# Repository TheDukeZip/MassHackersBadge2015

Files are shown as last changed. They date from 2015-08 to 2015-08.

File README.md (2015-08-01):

# MassHackersBadge2015

## Programming

The stock firmware is written in the Arduino IDE. Before making modifications, you should make sure you can properly flash the stock code before going wild. You will need:

* Arduino IDE (Recommend 1.6.5)
* <a href="https://www.pjrc.com/teensy/td_download.html">Teensyduino</a> plugin for Arduino

During the Teensyduino plugin, it will ask you any additional libraries you wish to install. **You must minimally install the SoftPWM library**, which is a pulse width modulation library which allows the badge to fade the LEDs in and out instead of just turn them on and off.

When flashing the Teensy module, use the following settings found under the Arduino menu *Tools*

* Board: "Teensy 2.0"
* CPU Speed: "8 MHz"

It is **VERY IMPORTANT** to set the speed to *8 MHz* or lower. Your teensy board is modified to operate at 3.3 volts instead of the default 5 volts. **Running at the default 16MHz is OVERCLOCKING** the processor, which will probably work fine for a while, but I can't guarantee how long it will last in the desert heat. Don't freak out if you do it by accident and the LEDs flash extra fast, just reflash again with the correct clock speed.

The Arduino IDE will then prompt you to press the reset button on the Teensy module, after which it will flash the board. You must press the reset button, since access to the bootloader through USB is disabled in the badge firmware to save power.

The Teensy module can be removed from the badge, and is populated with headers so you can pop it into a breadboard and use it for any other project you desire. Remember it has been modified to run at 3.3 volts, if you need to switch it back to 5 volts for other uses, <a href="https://www.pjrc.com/teensy/3volt.html">follow the instructions here at the part "If you decide to switch back to 5 volts..."</a>

## Firmware

### Adding a new color into the rotation
* Insert color into the `LED_COLOR` enum of the header file, ideally somewhere before `LED_COLOR_WHITE`
* Insert the RGB color values into the main file, `LEDColorMap` in the order it was inserted into `LED_COLOR` You will also need to increase the array size to accomodate this

That's it! The color automatically gets inserted into the rotation upon flashing. There is a trick to the SoftPWM library. Let's say for example you create a color that is RED 127, GREEN 255, BLUE 0. And your fade in time is 1000ms. The red and green fade in at the same rate, so red reaches its full brightness after 500ms, but green continues to fade in for an additional 500ms. You can overcome this by individually setting the fade in/out component of the red portion of the LED to be double that of the green portion of the LED. I started some work on this in the function `offLEDCorrected()` but it is up to you to finish it, and write a complementary function for turning on the LEDs!

### Adding a new mode into the rotation
* Insert the mode into the `LED_MODE` enum of the header file, which *must* be before `LED_MODE_END`
* Set the LED fade in and fade out times for your mode in `LEDModeFadeTimes` in the main file. You will also need to change the size of the array to accomodate this
* Create a handler function that does whatever you want to the LEDs - See other modes for examples
* Add a call to your handler function in the main `loop()` case statement: `switch(currentMode)`

The button presses are not interrupt based, you should plan to call the function `checkButton()` at least after every 50ms during your mode. (This is not truely a 50ms delay due to running at 8MHz, it is closer to 100ms)

## Hardware

Schematic and PCB was designed in Eagle 6.6.0. Eagle does not pre-load the ground pours when loading the PCB design. After opening the PCB you should run the "rats nest" tool to populate the ground pours.

You can remove the Teensy 2.0 module from the badge and put it into a breadboard for other fun hardware projects. The Teensy board is modified to operate at 3.3 volts, if you need to switch it back to 5 volts for other uses, <a href="https://www.pjrc.com/teensy/3volt.html">follow the instructions here at the part "If you decide to switch back to 5 volts..."</a>

### Errata

* Resistors for RED LEDs are R13 through R18 and should be 150 ohms
* Resistors for GREEN and BLUE LEDs are R1 through R12 and should be 15 ohms
* For the RGB LEDs in the BOM, the LED should be soldered on the board with the pin 1 marker on the bottom left, not the top right as on the silk screen

### BOM
| Qty | Description | MPN | Digikey PN |
|-----|---|-----|---|
| 1 | Teensy 2.0  | - |  - |
| 6 | RGB LED | CLVBA-FKA-CAEDH8BBB7A363 | CLVBA-FKA-CAEDH8BBB7A363CT-ND |
| 6 | 150 ohm 0603 resistor | RMCF0603FT150R | RMCF0603FT150RCT-ND |
| 12  | 15 ohm 0603 resistor  | RMCF0603FT15R0 | RMCF0603FT15R0CT-ND | 
| 1 | Voltage regulator for Teensy | MCP1825S-3302E/DB | MCP1825S-3302E/DB-ND |
| 2 | Header for Teensy board | PREC012SAAN-RC | S1012EC-12-ND |
| 2 | Socket for badge PCB | 929974-01-12-RK | 929974E-01-12-ND |
| 1 | CR123A Battery Holder | 1019 | 36-1019-ND |
| 1 | Momentary Switch | KMR231NG LFS | CKN10246CT-ND |

### Files

Eagle Project: **Hardware/MassHackersBadge2015.pro**<br>
Eagle Schematic: **Hardware/MassHackersBadge2015.sch**<br>
Eagle PCB: **Hardware/MassHackersBadge2015.brd**

Gerbers for manufacturing: **Hardware/Gerbers**

Design rule check and CAM file for Gerber generation for DirtyPCBs: **Hardware/DirtyPCBs**

### Available Hardware Pins

There are <a href="https://www.pjrc.com/teensy/pinout.html">3 pins</a> available on the Teensy 2.0 to add additional hardware:
* Pin 9 - Digital I/O
* Pin 10 - Digital I/O
* Pin 11 - Analog or Digital I/O

You will need to remove pins you use from the array `UnusedPins` so they do not get disabled during the power conservation routine

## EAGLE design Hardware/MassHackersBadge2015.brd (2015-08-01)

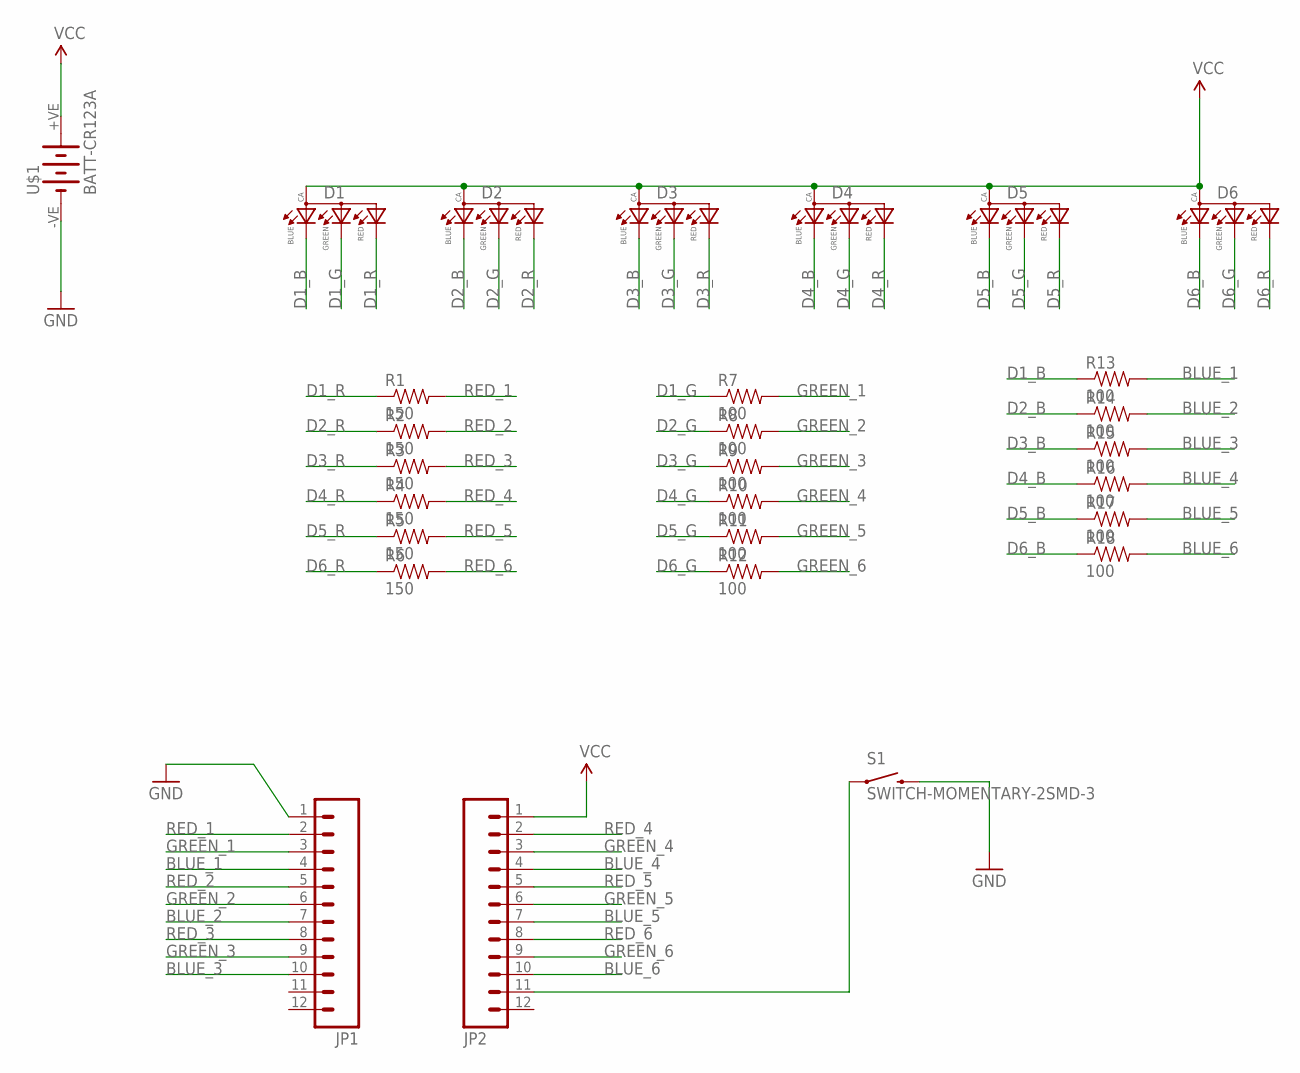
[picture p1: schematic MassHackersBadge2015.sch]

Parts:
D1, D2, D3, D4, D5, D6: 0.13_RGB_LEDPLCC; P-LCC-4-3
JP1, JP2: M12PTH; 1X12
R1, R2, R3, R4, R5, R6: 150; 0603-RES
R7, R8, R9, R10, R11, R12, R13, R14, R15, R16, R17, R18: 100; 0603-RES
S1: SWITCH-MOMENTARY-2SMD-3; TACTILE_SWITCH_SMD-3
U$1: BATT-CR123A; KEYSTONE-2/3A

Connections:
BLUE_1: JP1.4, R13.2
BLUE_2: JP1.7, R14.2
BLUE_3: JP1.10, R15.2
BLUE_4: JP2.4, R16.2
BLUE_5: JP2.7, R17.2
BLUE_6: JP2.10, R18.2
D1_B: D1.3 (BLUE), R13.1
D1_G: D1.2 (GREEN), R7.1
D1_R: D1.1 (RED), R1.1
D2_B: D2.3 (BLUE), R14.1
D2_G: D2.2 (GREEN), R8.1
D2_R: D2.1 (RED), R2.1
D3_B: D3.3 (BLUE), R15.1
D3_G: D3.2 (GREEN), R9.1
D3_R: D3.1 (RED), R3.1
D4_B: D4.3 (BLUE), R16.1
D4_G: D4.2 (GREEN), R10.1
D4_R: D4.1 (RED), R4.1
D5_B: D5.3 (BLUE), R17.1
D5_G: D5.2 (GREEN), R11.1
D5_R: D5.1 (RED), R5.1
D6_B: D6.3 (BLUE), R18.1
D6_G: D6.2 (GREEN), R12.1
D6_R: D6.1 (RED), R6.1
GND: JP1.1, S1.4 (2), U$1.-VE (-)
GREEN_1: JP1.3, R7.2
GREEN_2: JP1.6, R8.2
GREEN_3: JP1.9, R9.2
GREEN_4: JP2.3, R10.2
GREEN_5: JP2.6, R11.2
GREEN_6: JP2.9, R12.2
unnamed: JP2.11, S1.1
RED_1: JP1.2, R1.2
RED_2: JP1.5, R2.2
RED_3: JP1.8, R3.2
RED_4: JP2.2, R4.2
RED_5: JP2.5, R5.2
RED_6: JP2.8, R6.2
VCC: D1.4 (ANODE), D2.4 (ANODE), D3.4 (ANODE), D4.4 (ANODE), D5.4 (ANODE), D6.4 (ANODE), JP2.1, U$1.+VE (+)

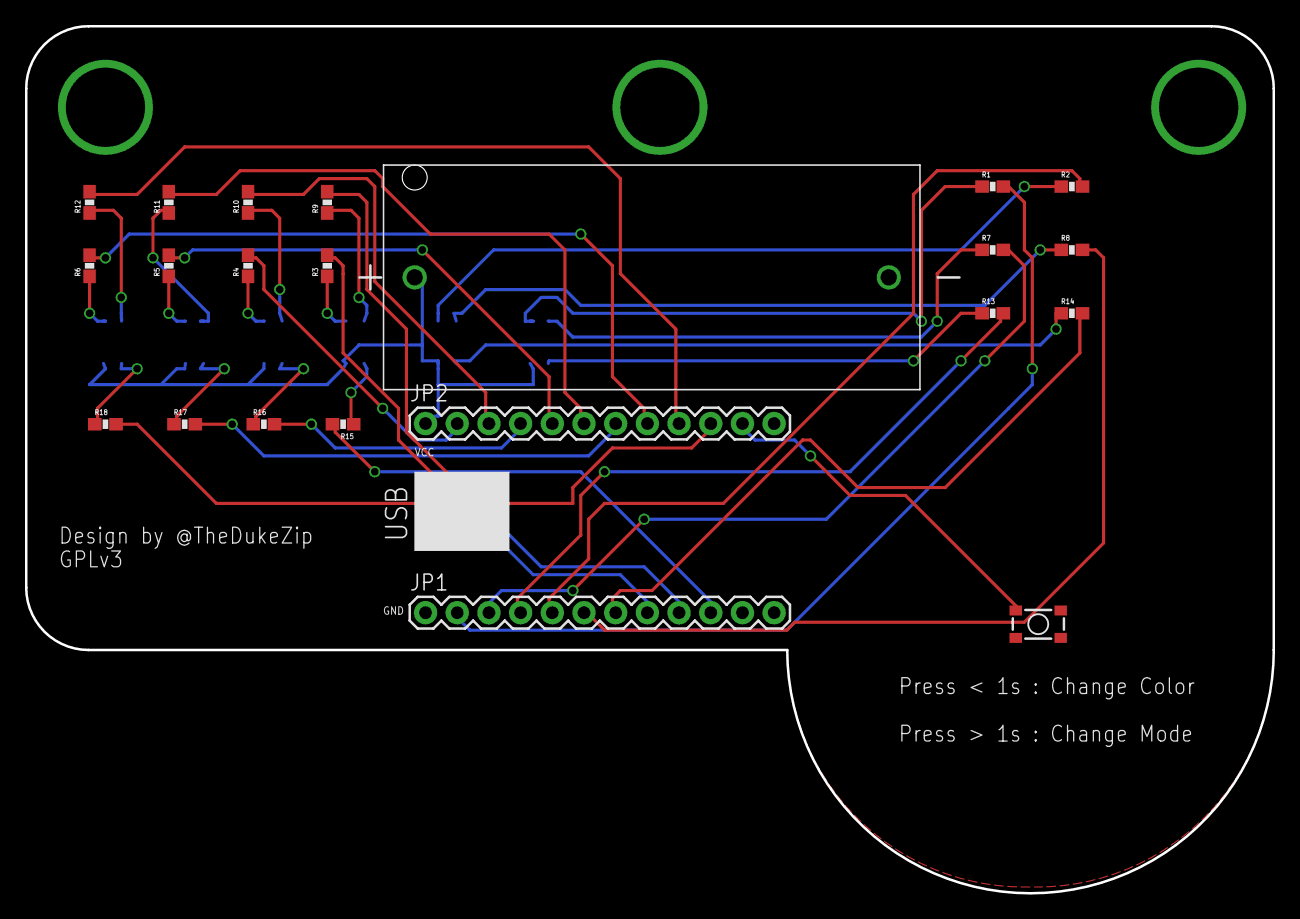
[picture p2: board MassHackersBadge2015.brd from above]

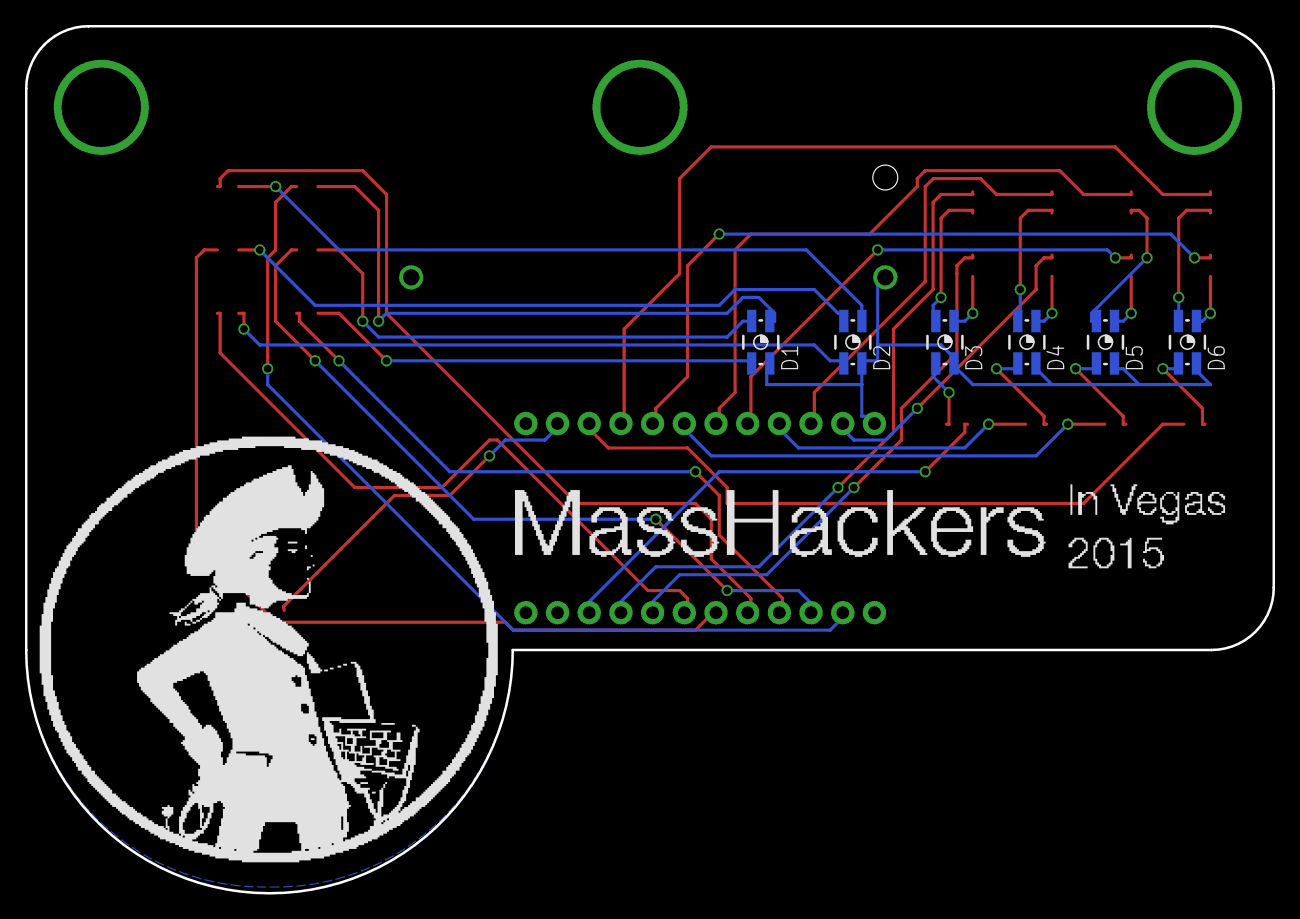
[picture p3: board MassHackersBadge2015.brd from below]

Board: 2 copper layers, 100.0 x 69.5 mm, 28 parts (6 on the bottom side), 39 nets.

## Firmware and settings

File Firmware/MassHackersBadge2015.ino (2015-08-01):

#include <SoftPWM.h>
#include <SoftPWM_timer.h>
#include <EEPROM.h>

#include "MassHackersBadge.h"


/////////////////////////////////////////////////////
//
// DEFINITIONS
//
/////////////////////////////////////////////////////

#define LED_BRIGHTNESS 1                        //Turn down the brightness - 0.5 = 50%   0.25 = 25% etc.

#define NUMBER_OF_LEDS 6                        //Number of LEDs on the badge to use

#define EEPROM_COLOR_LOCATION 0                 //Location in EEPROM to save color setting
#define EEPROM_MODE_LOCATION  1                 //Location in EEPROM to save mode setting
#define MAIN_LOOP_SAVE_ITERATIONS 60            //How many iterations through the main loop to check if you've changed the settings, and save them

#define BUTTON_PIN 12                           //Which pin is connected to the button?

#define CELLULAR_AUTOMATON_WIDTH 66             //Size of the array to store the cellular automaton state
#define CELLULAR_AUTOMATON_REPEAT_THRESHOLD 3   //If the LEDs for cellular automaton stabilize for this many iterations, reset the array
#define CELLULAR_AUTOMATON_OFFSET 30            //Offset in cellular automaton array to display

#define POWER_CONSERVATION_ENABLE true          //Turns off unneeded peripherals on MCU
#define NUM_UNUSED_PINS 3                       //Define the unused pins we can set to output mode to save some power
uint8_t UnusedPins[NUM_UNUSED_PINS] = { 9, 10, 11 };

//Two-dimensional array specifying LED pins
// Each row represents an LED, array within represent pin for R, G, B in that order
// Do not change these unless you use the code with hardware other than the MassHackers 2015 badge
// See this page for pinouts: https://www.pjrc.com/teensy/pinout.html
uint8_t LEDS[6][3] = {
                      {2, 1, 0},  //D1 { R, G, B }
                      {5, 4, 3},  //D2 { R, G, B }
                      {8, 7, 6},  // etc.
                      {19, 20, 21},
                      {16, 17, 18},
                      {13, 14, 15}
};

//Map values of R, G, B, for each LED_COLOR defined in header file
uint8_t LEDColorMap[10][3] = {
                              {  0, 255,   0}, //LED_COLOR_GREEN
                              {  0,   0, 255}, //LED_COLOR_BLUE
                              {255,   0,   0}, //LED_COLOR_RED
                              {  0, 255, 255}, //LED_COLOR_CYAN
                              {255, 255,   0}, //LED_COLOR_YELLOW
                              {255,   0, 255}, //LED_COLOR_PURPLE
                              {255, 255, 255}, //LED_COLOR_WHITE
                              {255, 255, 255}, //LED_COLOR_SEQUENTIAL Just a placeholder
                              {255, 255, 255}  //LED_MODE_MULTI       Just a placeholder
};

//Map of fade in , fade out times for each LED_MODE defined in header file
uint16_t LEDModeFadeTimes[9][2] = {
                                {  50, 400 }, //LED_MODE_SCAN
                                {  50, 400 }, //LED_MODE_SCAN_CONSTANT
                                {2000,2000 }, //LED_MODE_PULSE
                                {  50, 200 }, //LED_MODE_HEARTBEAT
                                { 600, 400 }, //LED_MODE_CELLULAR_AUTOMATON
                                {   0, 500 }, //LED_MODE_TWINKLE
                                {   0, 100 }, //LED_MODE_BOOTS_AND_PANTS
                                {   0,  50 }, //LED_MODE_VU_METER
                                {   0, 500 }  //LED_MODE_PARTY_SHUFFLE
};


uint8_t cells[CELLULAR_AUTOMATON_WIDTH];          //Array to store the cellular automaton status

uint8_t ruleset[8] = { 0, 0, 0, 1, 1, 1, 1, 0 };  //Cellular automaton ruleset - default is RULE 30 (Chaotic)
                                                  //See http://mathworld.wolfram.com/ElementaryCellularAutomaton.html for diagrams of all rules

uint8_t cellular_automaton_repeat_count = 0;      //Store the number of times the cellular automaton LEDs have repeated


/////////////////////////////////////////////////////
//
// SETUP AND MAIN LOOP
//
/////////////////////////////////////////////////////
LED_COLOR currentColor = LED_COLOR_GREEN;
LED_MODE currentMode = LED_MODE_SCAN;

LED_COLOR currentSequentialColor = LED_COLOR_GREEN;

int saveCounter = 0;
  
void setup() 
{
  //Start saving power
  if(POWER_CONSERVATION_ENABLE) startPowerSave();
   
  //Set up SoftPWM
  SoftPWMBegin(SOFTPWM_INVERTED); //LEDs have a common anode, pull LOW to turn them ON (inverted)
  for (int i = 0; i < NUMBER_OF_LEDS; i++)
  {
    for (int j = 0; j < 3; j++)
      SoftPWMSet(LEDS[i][j], 0);
  }
  SoftPWMSetFadeTime(ALL, 50, 400);

  //Set up button
  pinMode(BUTTON_PIN, INPUT);
  digitalWrite(BUTTON_PIN, HIGH); 

  //Restore settings
  restoreSettings();

  //Initialize cellular automaton array
  initializeCellularAutomaton();
}

void loop() 
{
  
  switch(currentMode) {
    case LED_MODE_SCAN:
      scan();
      break;

     case LED_MODE_SCAN_CONSTANT:
      scan_constant();
      break;

     case LED_MODE_PULSE:
      pulse();
      break;

     case LED_MODE_HEARTBEAT:
      heartbeat();
      break;
      
     case LED_MODE_CELLULAR_AUTOMATON:
      cellular_automaton();
      break;
      
     case LED_MODE_TWINKLE:
      twinkle();
      break;

     case LED_MODE_BOOTS_AND_PANTS:
      boots_and_pants();
      break;

     case LED_MODE_VU_METER:
      vu_meter();
      break;

     case LED_MODE_PARTY_SHUFFLE:
      party_shuffle();
      break;

     case LED_MODE_END: //Should never get here, but disables the warning in the compiler
      break;
  }

  //Save settings occasionally
  if(++saveCounter >= MAIN_LOOP_SAVE_ITERATIONS)
  {
    saveSettings();
    saveCounter = 0;
  }

  //If you're in sequential color mode, change the color on every iteration of the loop
  if(currentColor == LED_COLOR_SEQUENTIAL)
    changeSequentialColor();
}


/////////////////////////////////////////////////////
//
// LIGHTING MODE PROGRAMMING
//
//
// One handler function per mode
// Functions are called by the main loop() above
//
/////////////////////////////////////////////////////

//OCCASIONAL CYLON / KITT STYLE SCANNER
void scan() 
{
  int i;
  
  setLED(0, currentColor);

  delay(50);
  for (i = 0; i < NUMBER_OF_LEDS - 1; i++)
  {
    setLED(i+1, currentColor);
    offLED(i);
    delay(50);
    if(checkButton()) return;
  }

  for (int t = 0; t < 4; t++)
  {
    delay(50);
    if(checkButton()) return;
  }
  
  for (i = NUMBER_OF_LEDS - 1; i > 0; i--)
  {
    setLED(i-1, currentColor);
    offLED(i);
    delay(50);
    if(checkButton()) return;
  }

  offLED(0);
  
  for (int t = 0; t < 20; t++)
  {
    delay(50);
    if (checkButton()) return;
  }
}

//CONSTANT CYLON / KITT STYLE SCANNER
void scan_constant() 
{
  int i;
  
  setLED(0, currentColor);

  delay(50);
  for (i = 0; i < NUMBER_OF_LEDS - 1; i++)
  {
    setLED(i+1, currentColor);
    offLED(i);
    delay(50);
    if (checkButton()) return;
  }

  for (int t = 0; t < 4; t++)
  {
    delay(50);
    if (checkButton()) return;;
  }
  
  for (i = NUMBER_OF_LEDS - 1; i > 0; i--)
  {
    setLED(i-1, currentColor);
    offLED(i);
    delay(50);
    if(checkButton()) return;
  }

  for (int t = 0; t < 4; t++)
  {
    delay(50);
    if (checkButton()) return;
  }
}

//PULSE
void pulse()
{
  int i;
  
  for(i = 0; i < NUMBER_OF_LEDS; i++)
  {
    setLED(i, currentColor);
  }

  for (int t = 0; t < 16; t++)
  {
    delay(50);
    if (checkButton()) return;
  }
  
  for(i = 0; i < NUMBER_OF_LEDS; i++)
  {
    offLED(i);
  }

  for (int t = 0; t < 30; t++)
  {
    delay(50);
    if (checkButton()) return;
  }
}

//HEARTBEAT
void heartbeat()
{
  int i;
  
  for(i = 3; i < NUMBER_OF_LEDS; i++)
  {
    setLED(i, currentColor);
    setLED(5 - i, currentColor);
  }

  delay(50);
  if (checkButton()) return;  

  for(i = 0; i < NUMBER_OF_LEDS / 2; i++)
  {
    offLED(i);
    offLED(5 - i);
  }

  if (checkButton()) return; 
  
  for(i = 3; i < NUMBER_OF_LEDS; i++)
  {
    setLED(i, currentColor);
    setLED(5 - i, currentColor);
  }

  delay(50);
  if (checkButton()) return;  

  for(i = 0; i < NUMBER_OF_LEDS / 2; i++)
  {
    offLED(i);
    offLED(5 - i);
  }
  
  for (int t = 0; t < 30; t++)
  {
    delay(50);
    if (checkButton()) return;
  }
}

//CELLULAR AUTOMATON
void cellular_automaton() 
{
  int i;
  bool LEDs_repeated = true;
  uint8_t newcells[CELLULAR_AUTOMATON_WIDTH];  

  //Turning off the LEDs, then on, seems to be more visually appealing than doing it all in one loop
  for(i = 0; i < NUMBER_OF_LEDS; i++)
  {
    if(!cells[i + CELLULAR_AUTOMATON_OFFSET])
      offLED(i);
  }
  for(i = 0; i < NUMBER_OF_LEDS; i++)
  {
    if(cells[i + CELLULAR_AUTOMATON_OFFSET])
      setLED(i, currentColor);
  }
      
  for(i = 1; i < CELLULAR_AUTOMATON_WIDTH - 2; i++)
  {
    uint8_t left = cells[i-1];
    uint8_t middle = cells[i];
    uint8_t right = cells[i+1];

    newcells[i] = cellular_automaton_rules(left, middle, right);
  }

  //Far left cell
  newcells[0] = cellular_automaton_rules(0, cells[0], cells[1]);

  //Far right cell
  newcells[CELLULAR_AUTOMATON_WIDTH - 1] = cellular_automaton_rules(cells[CELLULAR_AUTOMATON_WIDTH - 2], cells[CELLULAR_AUTOMATON_WIDTH - 1], 0);

  //Check and see if the LEDs repeated
  for(i = 0; i < NUMBER_OF_LEDS; i++)
  {
    if(newcells[i + CELLULAR_AUTOMATON_OFFSET] != cells[i + CELLULAR_AUTOMATON_OFFSET])
      LEDs_repeated = false;
  }
  if(LEDs_repeated) 
    cellular_automaton_repeat_count++;

  memcpy(cells, newcells, CELLULAR_AUTOMATON_WIDTH * sizeof(char)); // I know you just did a double take. I put that there just to make you smile  ;)

  if (checkButton()) return;
  for (int t = 0; t < 20; t++)
  {
    delay(50);
    if (checkButton()) return;
  }

  //If the LEDs repeated too many times, reset the array
  if(cellular_automaton_repeat_count >= CELLULAR_AUTOMATON_REPEAT_THRESHOLD)
    initializeCellularAutomaton();
}
uint8_t cellular_automaton_rules(uint8_t a, uint8_t b, uint8_t c)
{
    if      (a == 1 && b == 1 && c == 1) return ruleset[0];
    else if (a == 1 && b == 1 && c == 0) return ruleset[1];
    else if (a == 1 && b == 0 && c == 1) return ruleset[2];
    else if (a == 1 && b == 0 && c == 0) return ruleset[3];
    else if (a == 0 && b == 1 && c == 1) return ruleset[4];
    else if (a == 0 && b == 1 && c == 0) return ruleset[5];
    else if (a == 0 && b == 0 && c == 1) return ruleset[6];
    else if (a == 0 && b == 0 && c == 0) return ruleset[7];
    return 0;    //Should never get here!
}

//TWINKLE RANDOM COLORS ON RANDOM LEDS
//Party modes should return true if checkButton() returns true to assist with breaking out of party shuffle
bool twinkle() 
{
  int lastLED = -1; //Store last LED lit so you never twinkle the same LED twice in a row
  int led = -1;

  randomSeed(millis());

  //Party modes should last for approx 3.2s or 8 'beats' to assist with "Party Shuffle"
  for (int i = 0; i < 21; i++)
  {
    //Select random LED
    while(led == lastLED) led = random(0, NUMBER_OF_LEDS);
    lastLED = led;
  
    //Select random color
    long color = random(0, (uint8_t)LED_COLOR_WHITE + 1);   //Don't randomly select sequential / multi
  
    setLED(led, (LED_COLOR)color);
    delay(25);
    if (checkButton()) return true;
    offLED(led);
  
    delay(25);
    if (checkButton()) return true;
  }

  return false;
}

//RANDOM COLOR ALL LED FLASH AT ~120BPM
//Party modes should return true if checkButton() returns true to assist with breaking out of party shuffle
bool boots_and_pants()
{
  int i;

  randomSeed(millis());

  //Party modes should last for 8 'beats' to assist with "Party Shuffle"
  for(int j = 0; j < 8; j++)
  {
    //Select random color
    long color = random(0, (uint8_t)LED_COLOR_END);   //Randomly selecting sequential or multi is ok and gives an occasional treat
    
    for(i = 0; i < NUMBER_OF_LEDS; i++)
    {
      setLED(i, (LED_COLOR)color);
    }
  
    for(i = 0; i < NUMBER_OF_LEDS; i++)
    {
      offLED(i);
    }
  
    if (checkButton()) return true;
  }

  return false;
}

//FAKE VU METER PEAKING ~150BPM
//Party modes should return true if checkButton() returns true to assist with breaking out of party shuffle
bool vu_meter()
{
  //Party modes should last for 8 'beats' to assist with "Party Shuffle"
  for(int i = 0; i < 8; i++)
  {
    setLED(0, LED_COLOR_GREEN);
    setLED(1, LED_COLOR_GREEN);
    setLED(2, LED_COLOR_GREEN);
    setLED(3, LED_COLOR_YELLOW);
    setLED(4, LED_COLOR_YELLOW);
    setLED(5, LED_COLOR_RED);
    if (checkButton()) return true;
    
    offLED(5);
    offLED(4);
    offLED(3);
    offLED(2);
    offLED(1);
    offLED(0);
    if (checkButton()) return true;
  }

  return false;
}

//CYCLE THROUGH ALL PARTY MODES
void party_shuffle()
{
  SoftPWMSetFadeTime(ALL, LEDModeFadeTimes[(uint8_t)LED_MODE_TWINKLE][0] / LED_BRIGHTNESS, LEDModeFadeTimes[(uint8_t)LED_MODE_TWINKLE][1] / LED_BRIGHTNESS);
  if(twinkle()) return;
  SoftPWMSetFadeTime(ALL, LEDModeFadeTimes[(uint8_t)LED_MODE_BOOTS_AND_PANTS][0] / LED_BRIGHTNESS, LEDModeFadeTimes[(uint8_t)LED_MODE_BOOTS_AND_PANTS][1] / LED_BRIGHTNESS);
  if(boots_and_pants()) return;
  SoftPWMSetFadeTime(ALL, LEDModeFadeTimes[(uint8_t)LED_MODE_VU_METER][0] / LED_BRIGHTNESS, LEDModeFadeTimes[(uint8_t)LED_MODE_VU_METER][1] / LED_BRIGHTNESS);
  if(vu_meter()) return;
}

//FLASHLIGHT MODE
// Not part of mode cycle, enabled by holding button for > 5s
void flashLight()
{
  int i;

  for(i = 0; i < NUMBER_OF_LEDS; i++)
    offLED(i);

  setLED(0, LED_COLOR_WHITE);
  setLED(1, LED_COLOR_WHITE);
  setLED(2, LED_COLOR_WHITE);
  setLED(3, LED_COLOR_WHITE);
  setLED(4, LED_COLOR_WHITE);
  setLED(5, LED_COLOR_WHITE);

  delay(1000);

  //Timeout after about 30 seconds
  for(i = 0; i < 500; i++)
  {
    delay(25);
    //Or exit if user pushes button
    if(checkButtonFlashlight())
      return;
  }

  for(i = 0; i < NUMBER_OF_LEDS; i++)
  offLED(i);
}


/////////////////////////////////////////////////////
//
// HELPER FUNCTIONS
//
/////////////////////////////////////////////////////
void startPowerSave()
{
  //Disable USB - saves ~4mA at 3.3V & 8MHz
  // Reprogramming the teensy will require a press of the teensy's reboot button
  Serial.end();
  
  //Disable ADC - saves ~0.8mA
  ADCSRA = 0;

  //Set unused pins to output mode - saves ~0.4mA
  for(int i = 0; i < NUM_UNUSED_PINS; i++)
    pinMode(UnusedPins[i], OUTPUT);
}

void changeColor() 
{  
  currentColor = (LED_COLOR)((uint8_t)currentColor + 1);  
  if (currentColor == LED_COLOR_END)
    currentColor = (LED_COLOR)0;

  //Flash currently selected color to user
  if(currentColor == LED_COLOR_SEQUENTIAL || currentColor == LED_COLOR_MULTI)
  {
    //Sequential/multi sees many-colors
    for(int i = 0; i < NUMBER_OF_LEDS; i++)
      setLED(i, (LED_COLOR)i);
    delay(25);
    for(int i = 0; i < NUMBER_OF_LEDS; i++)
      offLED(i);    
  }
  else
  {
    //Otherwise just show color selected
    for(int i = 0; i < NUMBER_OF_LEDS; i++)
      setLED(i, currentColor);
    delay(25);
    for(int i = 0; i < NUMBER_OF_LEDS; i++)
      offLED(i);
  }

  //Reset the save counter so you have to leave the color on for a bit before it saves
  saveCounter = 0;
}

void changeSequentialColor() 
{  
  currentSequentialColor = (LED_COLOR)((uint8_t)currentSequentialColor + 1);  
  if (currentSequentialColor == LED_COLOR_SEQUENTIAL)
    currentSequentialColor = (LED_COLOR)0;
}

void changeMode() 
{
  currentMode = (LED_MODE)((uint8_t)currentMode + 1);
  if (currentMode == LED_MODE_END)
    currentMode = (LED_MODE)0;

  SoftPWMSetFadeTime(ALL, LEDModeFadeTimes[(uint8_t)currentMode][0] / LED_BRIGHTNESS, LEDModeFadeTimes[(uint8_t)currentMode][1] / LED_BRIGHTNESS);
    
  //Reset the save counter so you have to leave the mode on for a bit before it saves
  saveCounter = 0;
}

//Check the button state and take appropriate action
// Elite points if you modify this to use an interrupt
// but this is A) Easy for non-embedded people to understand -and-
//             B) Gives the benefit of built in debounce
// In hindsight interrupt based code probably would be easier to understand than this mess
bool checkButton() 
{
  int holdCount = 0;
  
  if (!digitalRead(BUTTON_PIN))
  {
    //User pressed the button, shut all LEDs off in preparation
    // to show feedback to user
    for(int i = 0; i < NUMBER_OF_LEDS; i++)
      offLED(i);

    //See if they let go < 1s - change color
    for(int i = 0; i < 4; i++)
    {
      delay(50);
      if (digitalRead(BUTTON_PIN))
      {
        changeColor();
        delay(50);
        return false;
      } 
    }

    //User held down for > 1s, flash for feedback to user
    //Flash currently selected color to user
    for(int i = 0; i < NUMBER_OF_LEDS; i++)
      setLED(i, currentColor);
    delay(25);
    for(int i = 0; i < NUMBER_OF_LEDS; i++)
      offLED(i);
    
    while (!digitalRead(BUTTON_PIN))
    {
      delay(50);
      holdCount++;
      //If user held down for >5s, enable flashlight
      if(holdCount > 25)
        flashLight();
    }

    //Only change mode if user didn't enable the flashlight
    if(holdCount <= 25)
      changeMode();
    return true;
  }

  return false;
}

//Check button status during flashlight mode
// If user presses button, turn off white LEDs and exit
bool checkButtonFlashlight()
{
  if (!digitalRead(BUTTON_PIN))
  {
    for(int i = 0; i < NUMBER_OF_LEDS; i++)
      offLED(i);
    return true;
  }

   return false;
}

void saveSettings()
{
    //The update function only writes to EEPROM if the value has changed
    EEPROM.update(EEPROM_COLOR_LOCATION, (uint8_t)currentColor);
    EEPROM.update(EEPROM_MODE_LOCATION, (uint8_t)currentMode);
}

void restoreSettings()
{
  if((uint8_t)EEPROM.read(EEPROM_COLOR_LOCATION) < (uint8_t)LED_COLOR_END)
    currentColor = (LED_COLOR)EEPROM.read(EEPROM_COLOR_LOCATION);

  if((uint8_t)EEPROM.read(EEPROM_MODE_LOCATION) < (uint8_t)LED_MODE_END)
  {
    currentMode = (LED_MODE)EEPROM.read(EEPROM_MODE_LOCATION);
    SoftPWMSetFadeTime(ALL, LEDModeFadeTimes[(uint8_t)currentMode][0] / LED_BRIGHTNESS, LEDModeFadeTimes[(uint8_t)currentMode][1] / LED_BRIGHTNESS);
  }

}

void setLED(uint8_t ledNumber, LED_COLOR color)
{
  //If the user is in sequential color mode, we need a little extra trickery
  if(color == LED_COLOR_SEQUENTIAL)
    color = currentSequentialColor;

  //If the user is in multi color mode, there is bonus trickery
  else if(color == LED_COLOR_MULTI)
  {
    color = currentSequentialColor;
    changeSequentialColor();
  }
  
  SoftPWMSet(LEDS[ledNumber][0], LEDColorMap[(uint8_t)color][0] * LED_BRIGHTNESS);
  SoftPWMSet(LEDS[ledNumber][1], LEDColorMap[(uint8_t)color][1] * LED_BRIGHTNESS);
  SoftPWMSet(LEDS[ledNumber][2], LEDColorMap[(uint8_t)color][2] * LED_BRIGHTNESS);
}

void offLED(uint8_t ledNumber)
{
  SoftPWMSet(LEDS[ledNumber][0], 0);
  SoftPWMSet(LEDS[ledNumber][1], 0);
  SoftPWMSet(LEDS[ledNumber][2], 0);
}

void offLEDCorrected(uint8_t ledNumber, uint8_t currentIntensity, uint8_t fadeTime)
{
  SoftPWMSetFadeTime(LEDS[ledNumber][0], 0, (uint8_t)((float)255 / (float)currentIntensity * (float)fadeTime));
  SoftPWMSet(LEDS[ledNumber][0], 0);
  SoftPWMSetFadeTime(LEDS[ledNumber][1], 0, (uint8_t)((float)255 / (float)currentIntensity * (float)fadeTime));
  SoftPWMSet(LEDS[ledNumber][1], 0);
  SoftPWMSetFadeTime(LEDS[ledNumber][2], 0, (uint8_t)((float)255 / (float)currentIntensity * (float)fadeTime));
  SoftPWMSet(LEDS[ledNumber][2], 0);
}

void initializeCellularAutomaton()
{
  memset(cells, 0, CELLULAR_AUTOMATON_WIDTH * sizeof(char)); //I know you love to stare at any function that starts with 'mem'
  cells[CELLULAR_AUTOMATON_WIDTH / 2] = 1;
  cellular_automaton_repeat_count = 0;
}

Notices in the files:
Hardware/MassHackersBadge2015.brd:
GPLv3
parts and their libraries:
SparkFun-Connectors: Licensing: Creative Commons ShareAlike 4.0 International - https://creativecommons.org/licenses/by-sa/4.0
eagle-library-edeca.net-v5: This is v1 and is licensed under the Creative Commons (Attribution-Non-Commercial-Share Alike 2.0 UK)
